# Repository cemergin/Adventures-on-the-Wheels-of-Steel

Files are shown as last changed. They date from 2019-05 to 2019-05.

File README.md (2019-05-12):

# Adventures on the Wheels of Steel<sup>*</sup>

### Place blocks on the turntable

### Make some noise!

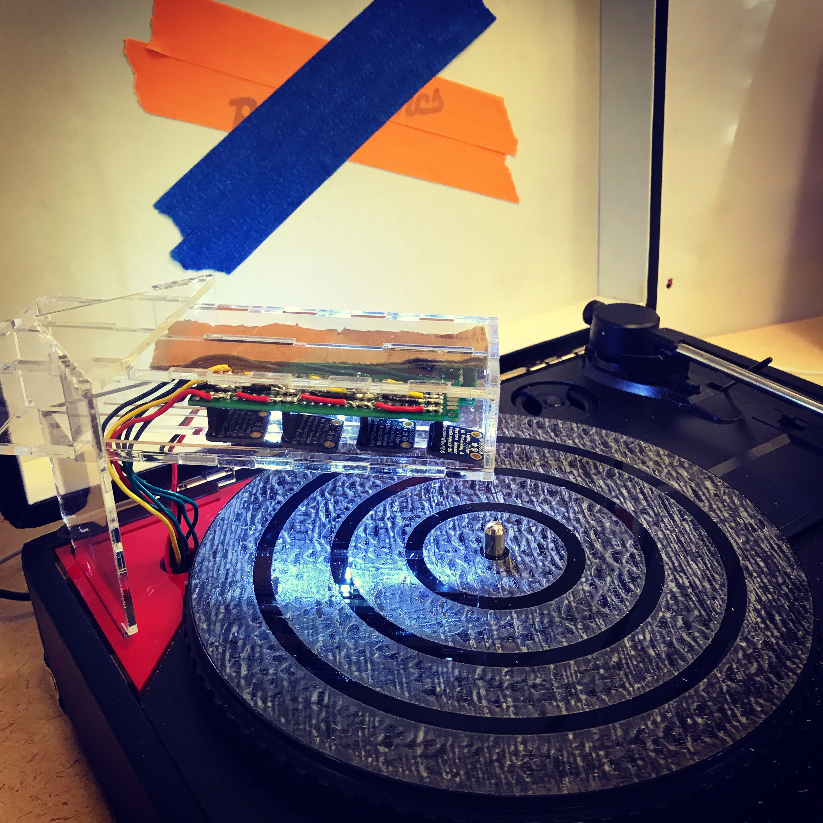
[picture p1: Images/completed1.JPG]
Adventures on the Wheels of Steel


## What is this?

*Adventures on the Wheels of Steel* is a tangible sequencer that allows users to create their own MIDI patterns by placing small objects, in this case lego blocks covered with colored tape, on a rotating disk found on turntables. The physical interface allows users to make beats, play chords or notes using the 4 channels. All channels are equiped with color recognition which creates room for greater variability. It utilizes Arduino Leonardo's native USB connectivity to tranfer MIDI messages to any Digital Audio Workstation imagenable. 
 
## Why is this made? 

The project has been created as part of 49-719 *Internet of Things - In Depth* class that I've attended at Carnegie Mellon University during Spring 2019 semester. *Adventures on the Wheels of Steel* pays homage to the legendary Grand Master Flash, who single handedly redefined the use of turntables in music, while investigating how tangible interfaces can ease and enchant the idea generation process during music making. 

## How did I end up here?

When I first entered electrical engineering school back in 2012, I had a dream of creating electronic music instruments, guitar pedals and amplifiers. Unfortunately, I learnt the hard way that undergraduate engineering school is not really the place where dreams come true. This is not true for graduate education though.

Long story short, when I was given the chance to work on any project idea I want for 6 weeks, I knew that I was going to create something to do with music. All the pieces came together when I stumbled upon the Beat Blox project created by Per Holmquist. I looked at his take on the turntable as a tool to create music and said "I can make that". Then for 6 weeks I focused my energy on replicating his design and trying to find ways of adding features that can make it more expressive and adaptable. I thought that to create a real music making tool, I needed to integrate MIDI to the design and add a way of creating variation.  

### Inspiration

I got most of my inspiration from this project. Its simple beautiful at the same time. Check it out before you continue to understand where I'm coming from.

[Beat Blox by Per Holmquist](https://open.spotify.com/track/7xMzNQkDzu3JZkhURGvH7p?si=wFec3MJkSc-wyBhV8cBQGQ)

### Forerunners

Tangible interfaces are not anything new for electronic music making tools. Here are some of the recent examples that I looked at while working on my design. The beauty of making things with technology is that when you figure out a way to make a particular tool, adapting your findings to create designs that are similar on the inside but different on the outside is easy. So here are some inspiration for everyone who wants to create their own MIDI controllers.   

[Spinning Disc Step Sequencer](https://learn.adafruit.com/spinning-disc-step-sequencer/overview)

[Coin Sequencer](http://www.varal.org/coinsequencer/)

[Tquencer](https://jensvetter.de/files/pdf/tquencer_acm.pdf)

[UTS-1](https://www.youtube.com/watch?v=3NAn9fSdh8M)

[XOXX Composer](http://xoxxcomposer.axelbluhme.se/)

## How can you make this? 

I've listed the components I used along with schematics and lasercutting patterns to recreate what I made below but I highyl recommend you look at the tutorial I created about MIDI and creating MIDI instruments with Arduino using the ling below. 

[Basic Tutorial on MIDI](https://github.com/cemergin/Adventures-on-the-Wheels-of-Steel/blob/master/Tutorials/MIDI101_%231.md)

Just hook up the components the way I described below and upload the code and you will be good to go. Design physical enclosure to taste and start making some noise! I hacked a already existing record player to use its rotating disk but you don't have to. If you know more mechatronics than me just do your thing and go nuts! 

### Components

1. 1 x Arduino Leonardo
1. 1 x [SparkFun Multiplexer Breakout - 8 Channel](https://www.sparkfun.com/products/13906)
1. 1 x [Byron Statics Record Player](https://www.amazon.com/gp/product/B07J2NZLZS/ref=ppx_yo_dt_b_asin_title_o03_s00?ie=UTF8&psc=1)
1. 4 x [Adafruit APDS9940](https://www.adafruit.com/product/3595) 
1. 4 x [Adafruit LED Sequins - Warm White](https://www.adafruit.com/product/1758)

### Circuit 

#### Basic Circuit 

I used this circuit as a proof of concept for my idea and extended the capabilities from here. I feel like starting small is always easier when you are developing projects such as this one. 

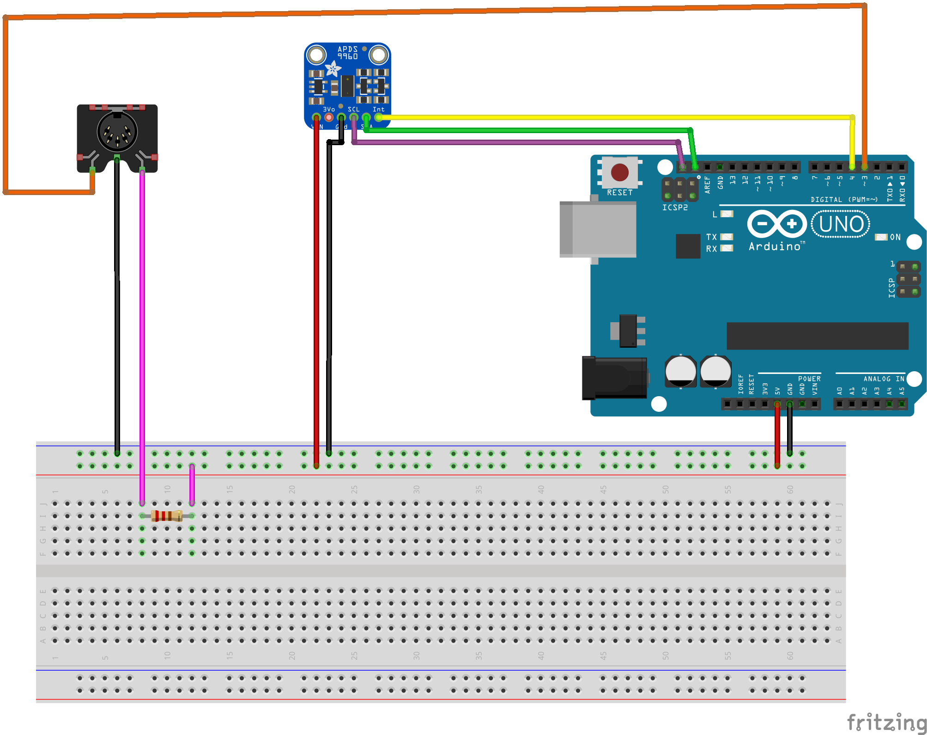
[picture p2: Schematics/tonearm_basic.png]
Basic Circuit


#### Initial Prototype

The initial prototype used a female MIDI jack to output MIDI information but that's not really convenient if you are mainly creating music with your computer. 

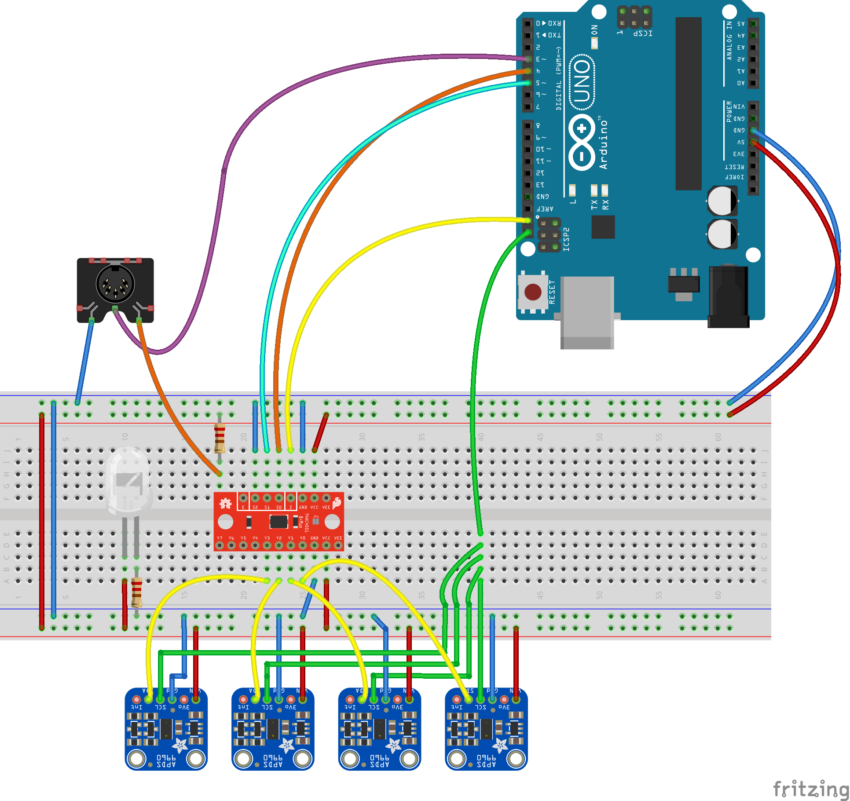
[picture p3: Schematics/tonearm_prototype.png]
Initial Prototype


#### Final Circuit

Arduino Leonardo for the resque!

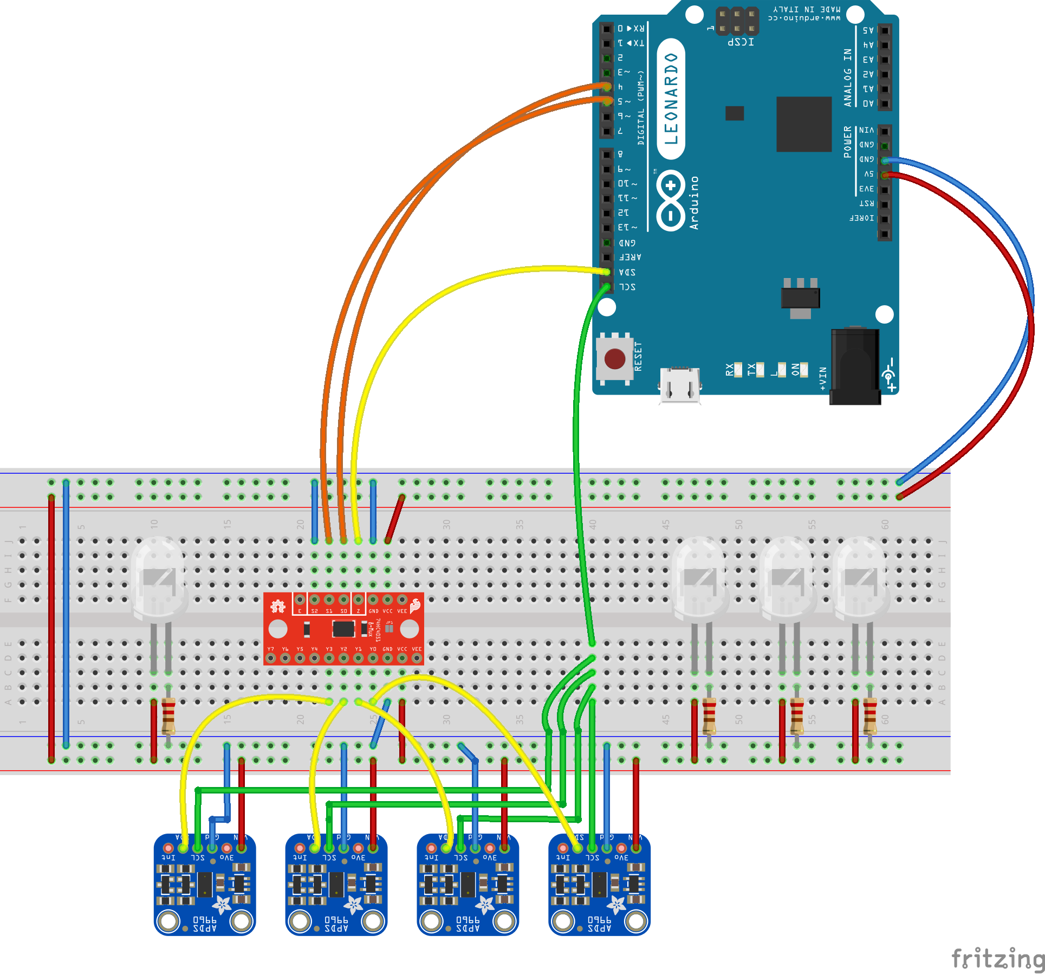
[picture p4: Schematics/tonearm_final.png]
Final Circuit


### Code

The code is pretty self explanatory. Check the comments I added to understand how it does what it does. 

[You can reach the final code here](/Code/tonearm.ino)

### Form  

First things first, I suck at CAD! On the other hand, I have a couple friends that are experts at it, so I got some help while designing the right enclosure for my circuit. 

#### "With A Little Help From My Friends"<sup>**</sup>

Final tonearm form designed by [Özgüç Bertuğ Çapunaman](https://github.com/ozgucbertug) on Rhino.

#### Tonearm

Tonearm Form

[Tonearm Lasercutting Pattern](tonearm.dxf)

## Related Resources

[Selfmade Tutorial on MIDI & Arduino](https://github.com/cemergin/Adventures-on-the-Wheels-of-Steel/blob/master/Tutorials/MIDI101_%231.md)

[Introduction to MIDI by the MIDI Association](https://www.midi.org/images/easyblog_articles/43/intromidi.pdf)

[MIDI Message Codes Explained](http://www.songstuff.com/recording/article/midi_message_format/)

[Arduino MIDI Output Basics](https://www.midi.org/articles-old/arduino-midi-output-basics)

[MIDI Output Using an Arduino](http://itp.nyu.edu/physcomp/labs/labs-serial-communication/lab-midi-output-using-an-arduino/)

[Arduino MIDIUSB Library](https://www.arduino.cc/en/Reference/MIDIUSB)

## Notes

* [Grandmaster Flash & the Furious Five - Adventures of Grand Master Flash On the Wheels of Steel](https://open.spotify.com/track/7xMzNQkDzu3JZkhURGvH7p?si=wFec3MJkSc-wyBhV8cBQGQ)

** [The Beatles - With A Little Help From My Friends](https://open.spotify.com/track/2RnPATK99oGOZygnD2GTO6?si=fi9PeBmyTsGBMCBx69-2zQ)

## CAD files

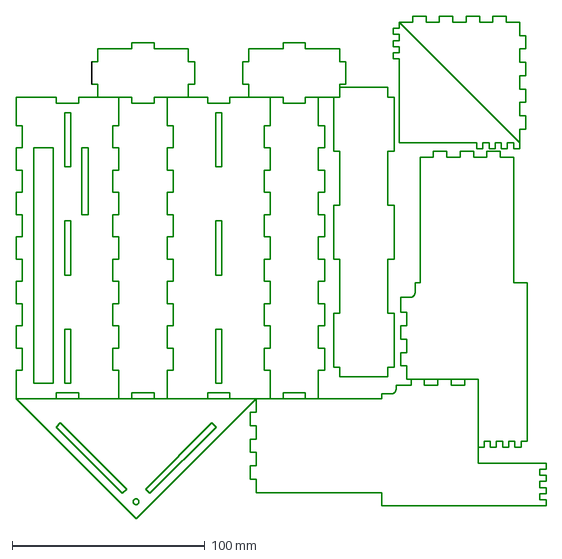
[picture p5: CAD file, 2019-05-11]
Form/tonearm.dxf
274.6 x 260.6 mm

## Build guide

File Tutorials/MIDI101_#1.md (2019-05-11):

# Introduction to MIDI (Pt.1)

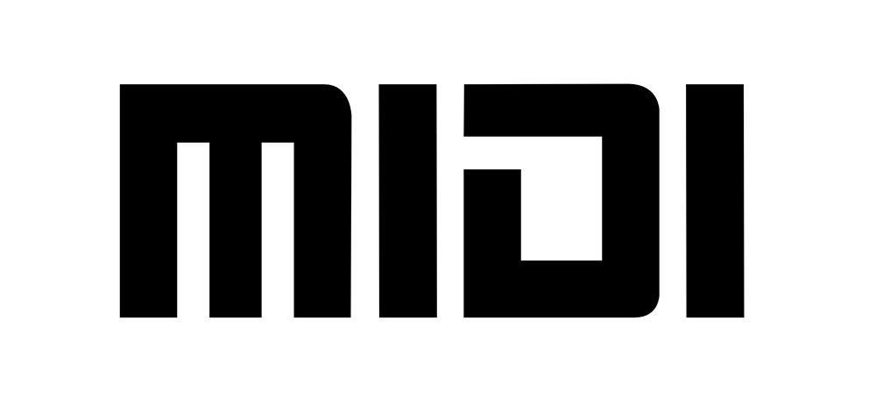
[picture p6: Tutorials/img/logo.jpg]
MIDI LOGO


# What is MIDI anyway?

Musical Instrument Digital Interface or better known as MIDI, is a technical standard that allows digital instructions to be sent between electronic music instruments and computers. The infamous standard incorporates a communication protocol, a digital interface and electrical connectors which in combination allows the communication of a variety of audio devices. 
 
MIDI instructions consist of simple digital data only! These instructions transfer information about pitch, tempo and velocity of musical notes. There are no actual audio signals involved. This aspect alone makes MIDI really compact, editable and easy to move around because the consumed disk space is thousand times less compared to an equivalent recorded audio. Musicians all around the world use it to play, edit and record music! 

Here's a simple flowchart to help you understand how it works.

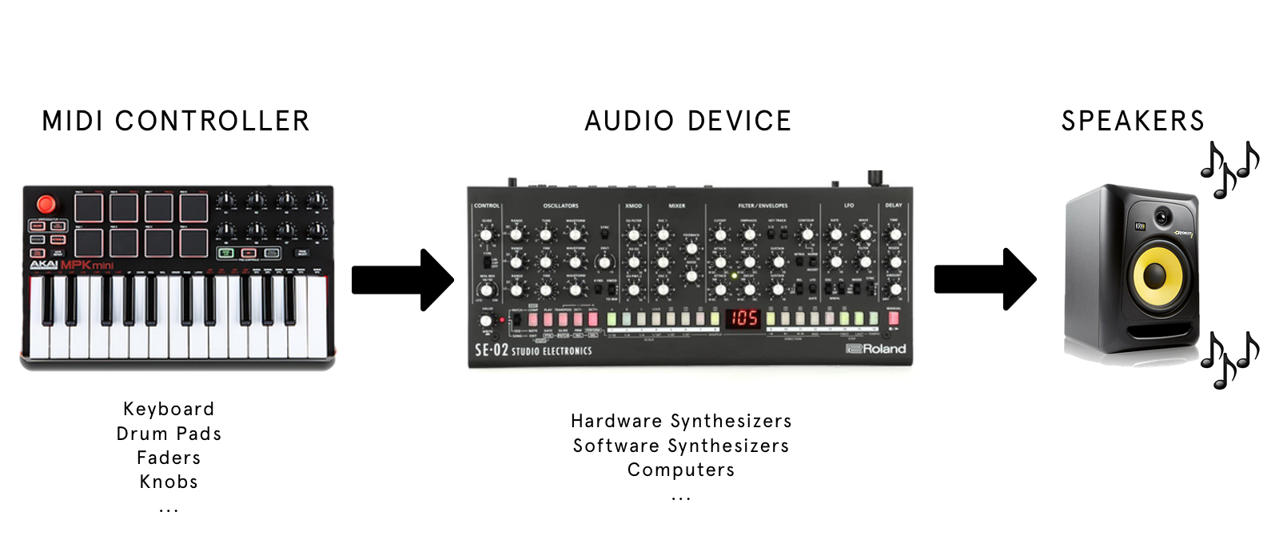
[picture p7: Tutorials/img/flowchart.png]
Simple flow Diagram


In simple terms, MIDI works like sheet music for electronic devices read and play. 

In more technical terms, MIDI messages work like computer code, they help generate and transfer instructions for electronic audio devices. A MIDI source, such as a keyboard, generates these instructions and through the MIDI cables, transfers them to an audio device. The audio device which is usually a synthesizer of some sort, in turn translates the instructions into real audio. 

The MIDI system is actually really similar to “player piano” if there any Western fans out there. Look closely to the sheet of paper that is rolling on the piano, you will see lines that are etched on it which instructs the mechanism which notes to play and for how long.  

### Player Piano

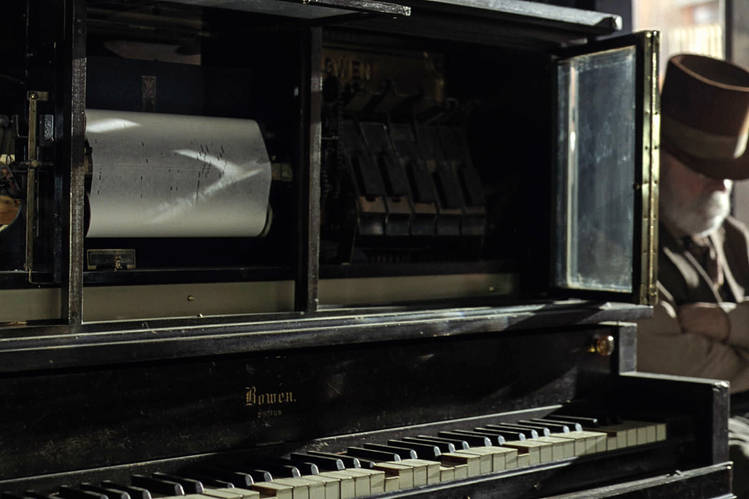
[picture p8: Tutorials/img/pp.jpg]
Player Piano


[The Entertainer on a player piano](https://www.youtube.com/watch?v=aseMAEctM1s)

Here’s how a MIDI file of Pokemon Red’s Pokecenter theme looks like on my Digital Audio Workstation. The annotations showcase some of the different types of information that can be transferred with MIDI.

This is how Ableton Live's piano roll looks like when I added the Pokecenter theme from the Pokemon Red game!

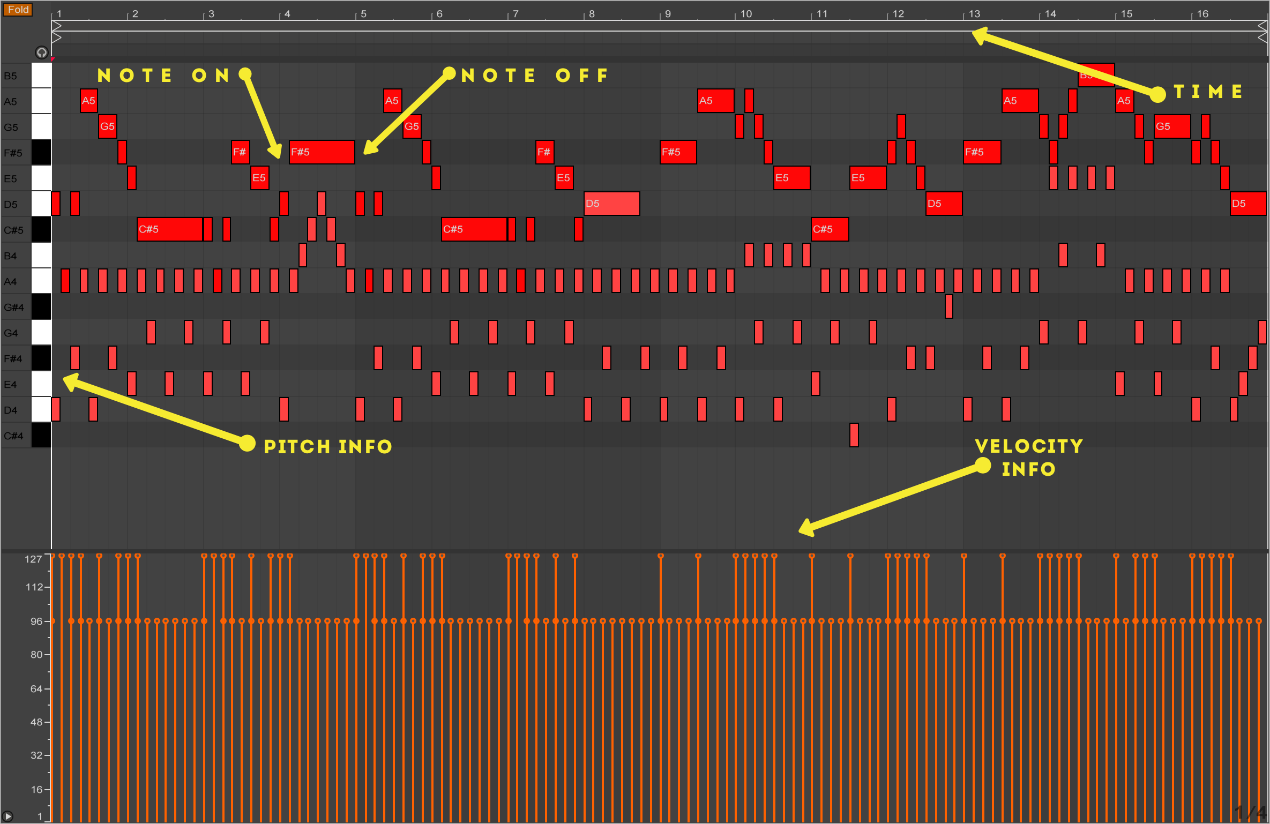
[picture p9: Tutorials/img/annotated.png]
Pokemon Song Picture


# Some History

As it turns out, there was no standardized way of connecting or synchronizing electronic music instruments manufactured by different companies in the early 1980s. Every manufacturer was trying to come up with their own way of communication between instruments. 

The founder of Roland, a company that has shaped the face of music multiple times in the last 50 years, Ikutaro Kakehashi felt that the lack of standardization was limiting the growth of the electronic music industry. He reached out to Sequential Circuits’s Dave Smith, another legendary name in the electronic music industry, about creating a cheap and simple standard in 1981. 

The initial standard was shown in November 1981 during the Audio Engineering Society and the first synthesizers that were equipped with MIDI hit the shelves in 1982. The rest was history! 

## Rolan Jupiter-6 one of the first two synthesizers with MIDI connectivity

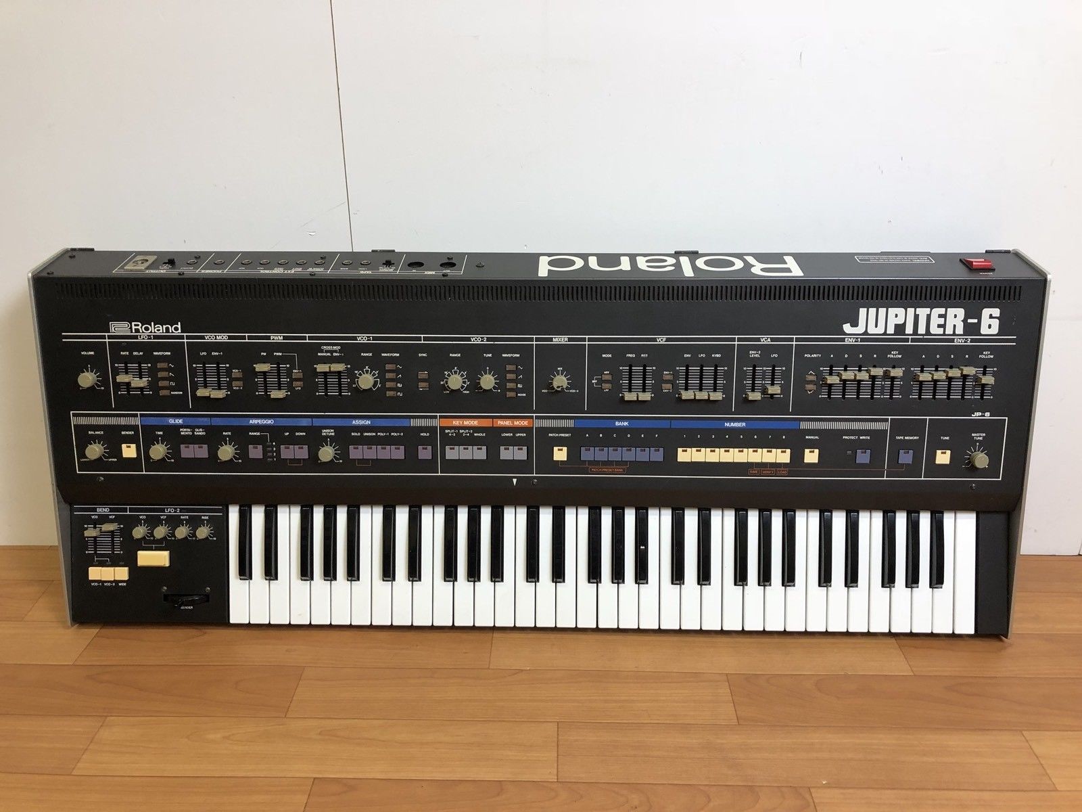
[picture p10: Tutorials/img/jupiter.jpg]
Roland Jupiter-6


No wonder there was a techno boom in the early 1990s all around the world! 

# Working with MIDI

Here's where things start to get interesting! Let's look at how you can connect MIDI capable products to your own computer. 

### Things you will need

* Your computer
  * Any computer with a decent processor and RAM will do here but Digital Audio Workstation; aka DAWs, tend to get processing heavy as the number of intrument channels increase. Since we are going to work with basic stuff, you should be alright with your good old laptop.
* A Digitial Audio Workstation
  * There are a lot of Digital Audio Workstations or DAWs out there. I use Ableton Live. You might also encounter Apple's Logic Pro, Steinberg's Cubase, Apple's Garage Band, FL Studio, Presonus Studio One, Propellerhead Reason, Avid's Pro Tools.. The list goes on and on. People who are into music production use more than one as each of them have their own pros and cons. Unfortunately, most of them are paid applications but if you don't want to break your piggy bank, there are ways around this which I'm not going to get into here ;) Just do a little Google search! 
* A software synthesizer
  * Luckyl, most DAWs come with a bunch of software synthesizers to play with! There are also numerous software syhtnesizers out there in the digital world. Some are free but most of them aren't cheap. Watch some Youtube reviews to make up your mind if you are interested. 
* A MIDI Controller
  * Any controller with MIDI capabilities work here. I have a Novation Launchkey 49 USB Keyboard at the moment which I will be using during this tutorial but your MIDI device doesnt have to be a keyboard. For example, Akai Professional's Pad controllers are also really fun to play with. The Karg nanoKey family is a good place to start. If you want to go hard with a lot of controls such as trigger pads, faders and knobs you might look into Arturia's KeyLab mkII series. Be warned though, they are not cheap.
  * One thing to distinguish here! Most of the controllers that are available on the market today connect to your computer through USB. Most of them also have the original MIDI inputs and outputs but they are seldom used to connect to computers. They are mostly there to communciate to analog synthesizers. The glorious days of using the original MIDI connection to make music may be past but the you can still run into some MIDI cables here and there.
* A soundcard with MIDI Input (Optional / Read Details) 
  * If you don't have a USB connected controller, you need a device to convert those MIDI messages for your computer to understand wats happening. Most USB connected soundcard have MIDI input and output today. So you might as well get one fi you are going to play with your fathers MIDI controllers that are collecting dust in the attic. 
  * Getting a soundcard will help with the latency issues during your recordings and production as most computers cannot really cope well with digital-2-analog conversion of signals. 
  * I'm using Roland's Quadcapture for a while now. I like it and its a good place to start. If you want other options look into brands like M-Audio, Focusrite, MOTU. If you don't want to take my word for it Google is your biggest companinon into the world of electronic music production. 
* A Male-Male MIDI Cable (Optional / Read Details) 
  * As you might guess, if you have a USB connected MIDI controller, you can skip this step but its always good to have one as MIDI cables can come in handy in situations where you work with olders synthesizers. 
* USB Cable(s) (Not so optional!)
  * I think you started to get the idea here. If you have USB connected tools like your MIDI controller or your soundcard, you better have a USB cable to connect them to your computer. 
 
# Let's Get Down to Business

### Follow These 5 Easy Steps To Start Producing Music 

1. Connect Your Controller To Your Computer
  1. How to connect your USB Controller
    1. This one is pretty self explanatory! Just find the appropriate USB cable for your controller and plug it in to your computer!
  1. How to connect with a MIDI Cable
    1. Similar to the USB Controller option, just connect Your Soundcard Through USB!
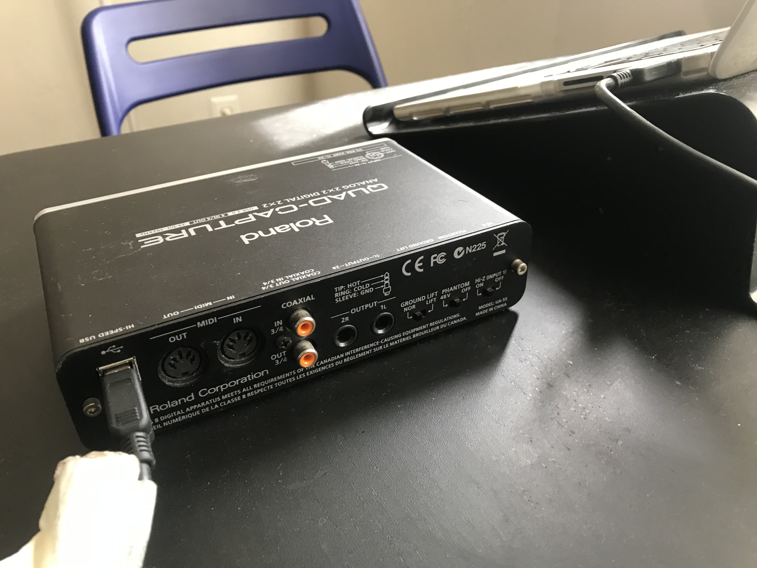
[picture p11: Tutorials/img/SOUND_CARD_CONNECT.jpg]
Connect Your Soundcard Through USB
    1. 
    1. Get your MIDI Cable & locate the MIDI Input
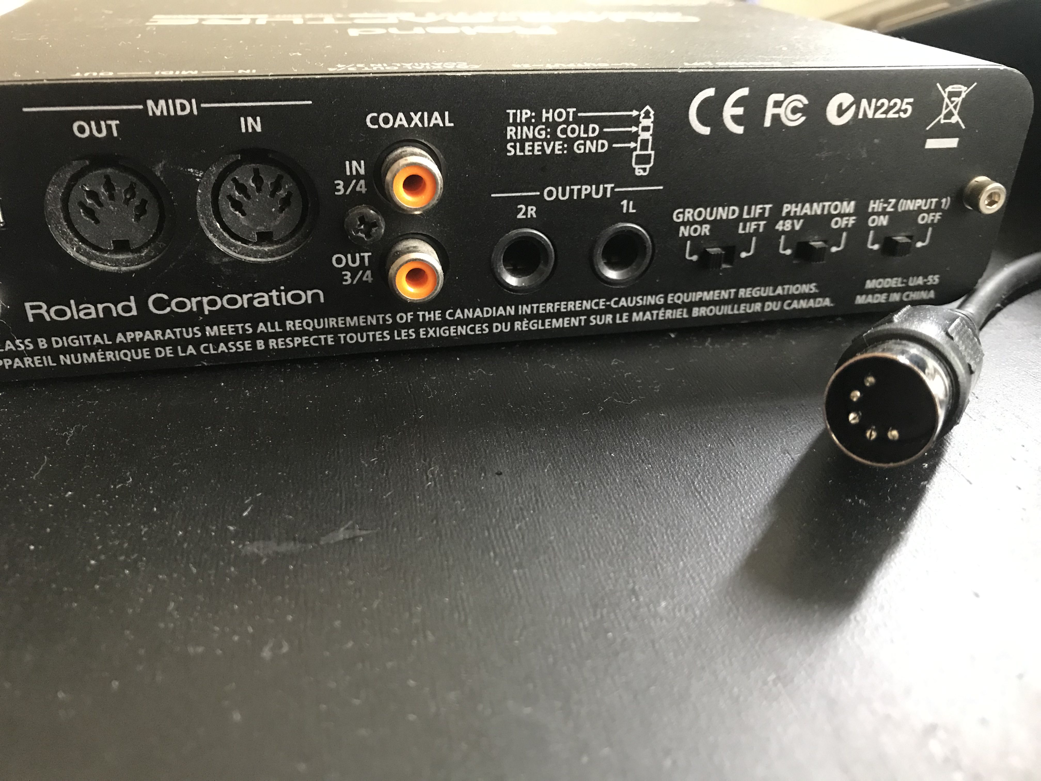
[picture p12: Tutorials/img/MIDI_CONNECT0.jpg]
Get your MIDI Cable & locate the MIDI Input
    1. 
    1. Connect MIDI Cable to MIDI Input Pin of your soundcard
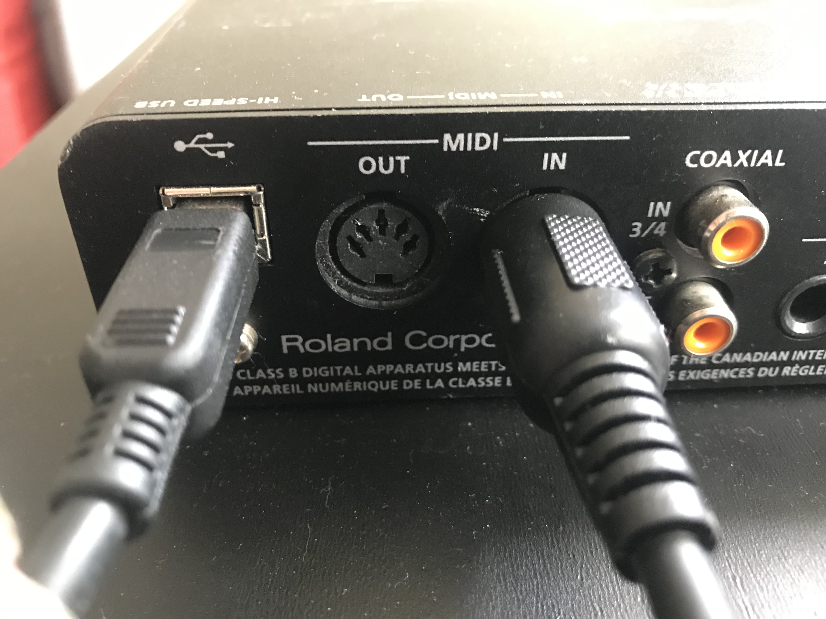
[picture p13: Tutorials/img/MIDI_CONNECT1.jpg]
Connect MIDI Cable to MIDI Input Pin of your soundcard
    1. 
    1. Connect the other end of your MIDI cable to MIDI Output device
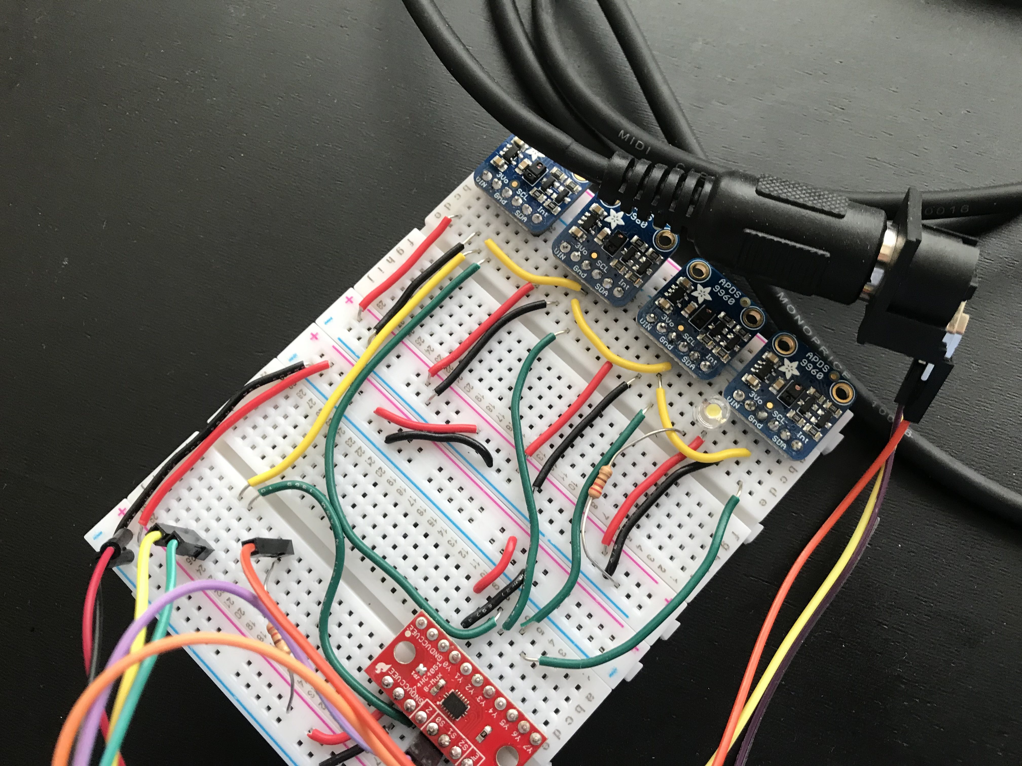
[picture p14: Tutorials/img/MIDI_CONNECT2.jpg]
Connect the other end of your MIDI cable to MIDI Output device
    1. 
1. Go to your DAW of choice
  1. Open up your DAW of choice. I'm using Ableton Live 9 here and this is how it looks like when I start it up.
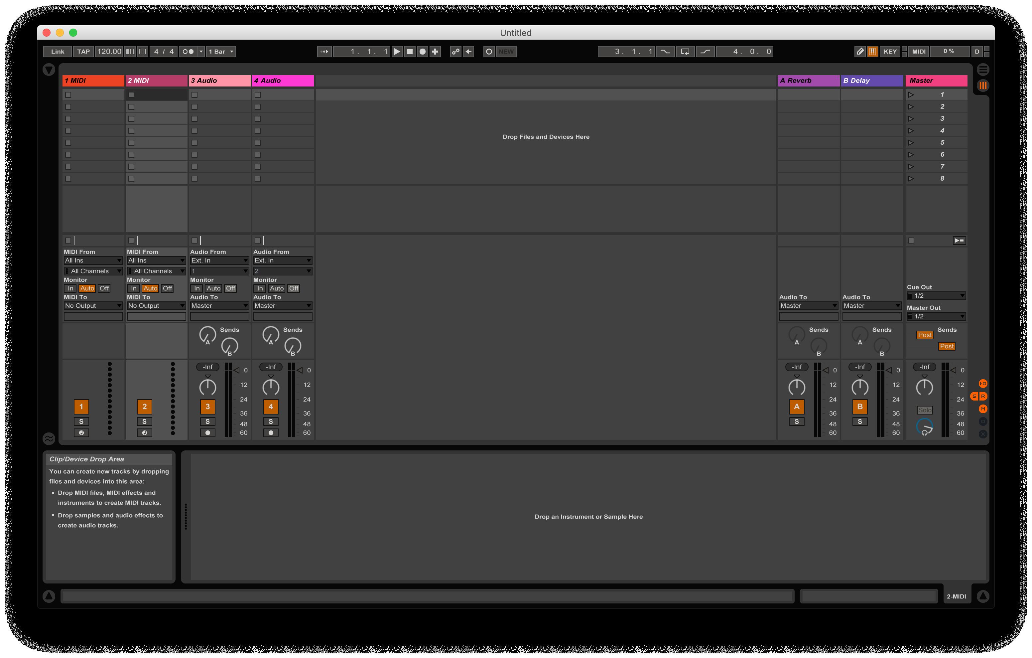
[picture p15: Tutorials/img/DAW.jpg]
How Ableton looks like
     
1. Throw your instrument of choice in the mix!
  1. Add your insturment of choice to the MIDI channel you want to work on your DAW. A simple drag and drop should work for Ableton. I used a instrument named Analog that ships with Ableton. 
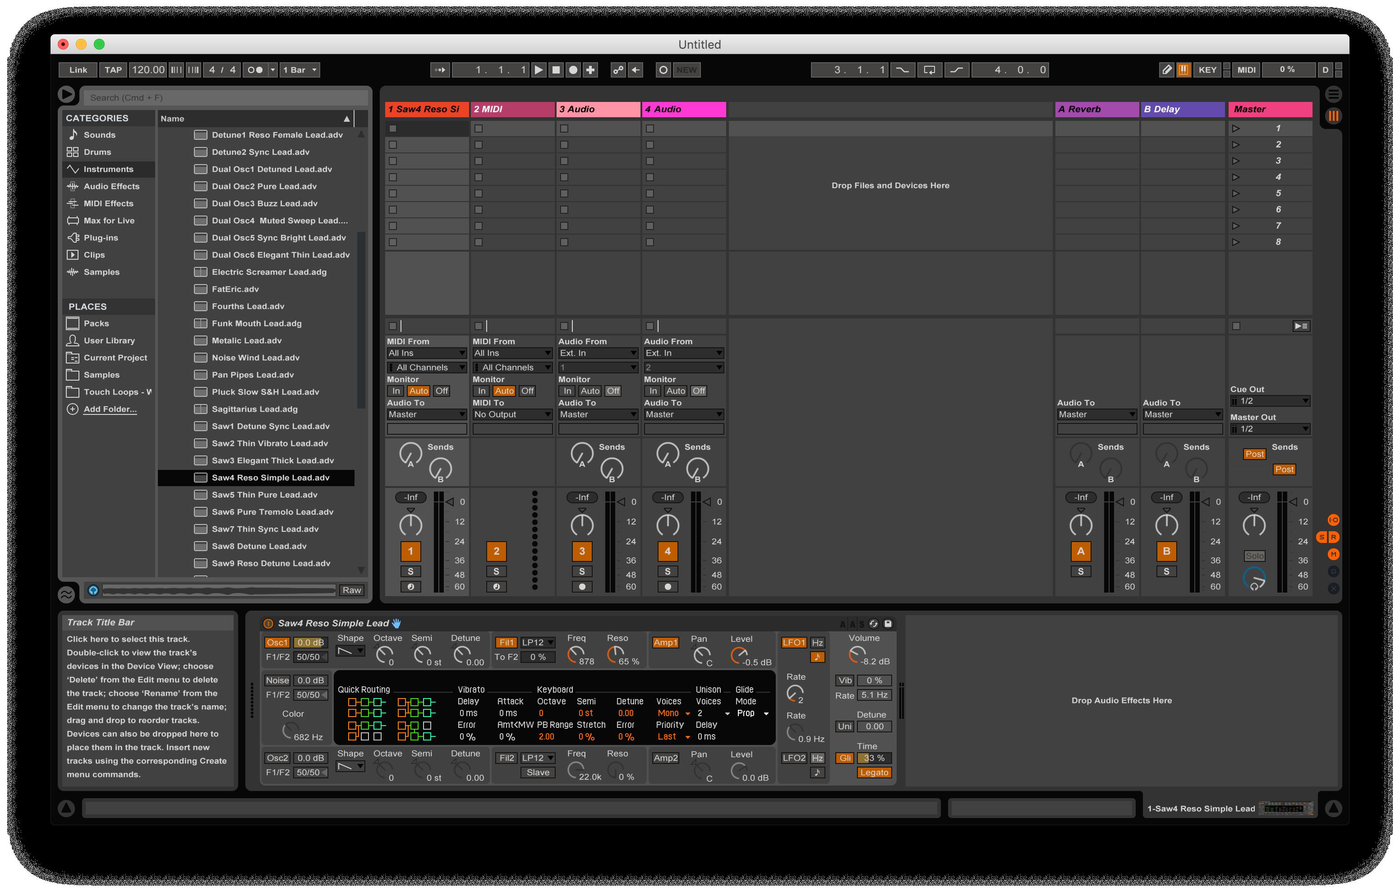
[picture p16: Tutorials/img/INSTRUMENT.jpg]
Choose an software sytnhesizer
     
1. Fiddling With Settings
   1. Now we need to let our DAW know which MIDI device were are looking for.
   1. Look at the MIDI input settings on your MIDI channel.
   1. Choose the right controller for your input.
     1. My Novation controller that I hooked up through USB looks something like this.
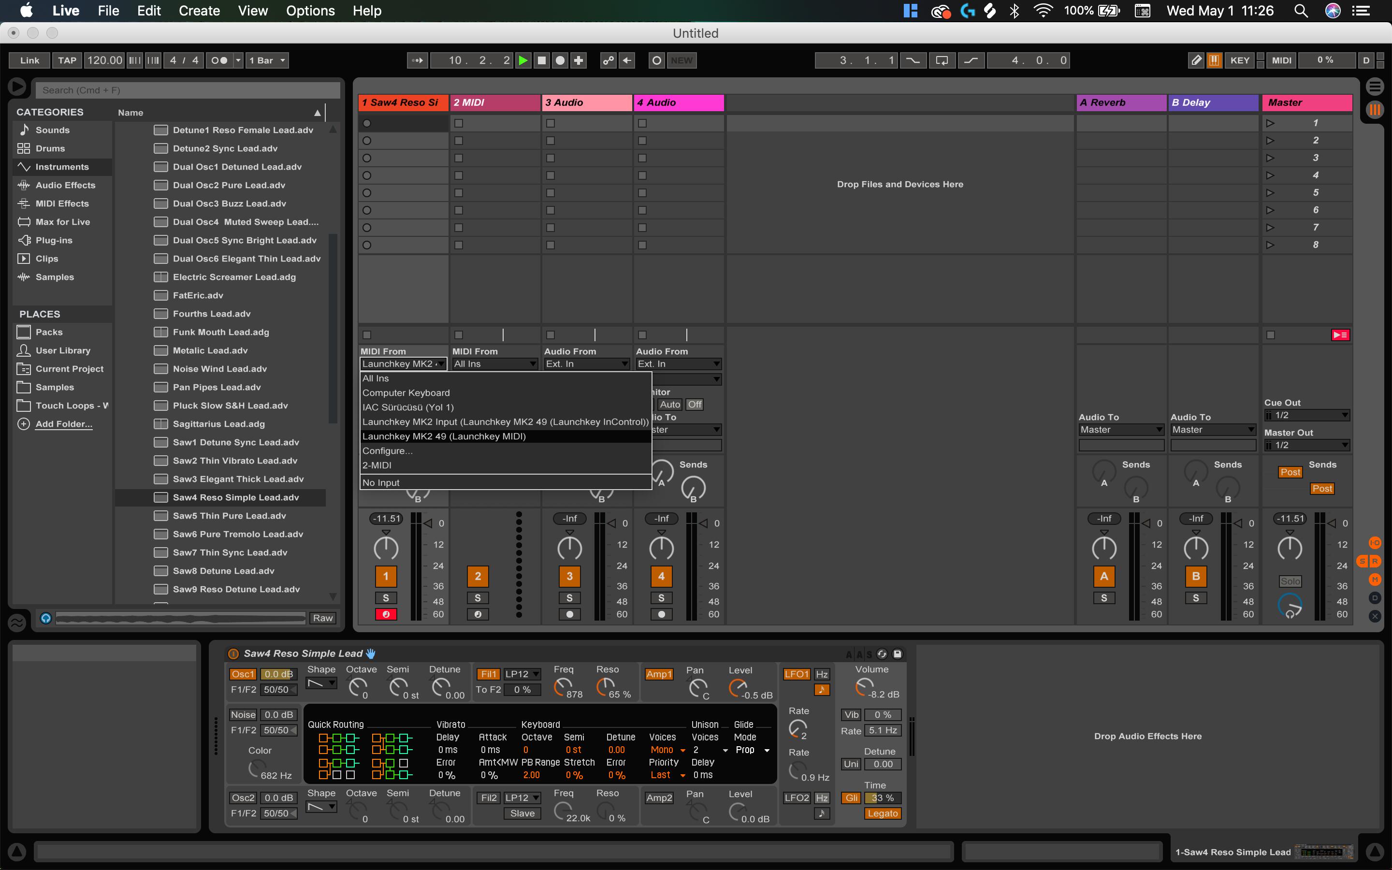
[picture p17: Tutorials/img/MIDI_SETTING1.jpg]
MIDI Settings no#1
     
     1. If you are using a Soundcard to communicate the MIDI messages to your computer. You should look for your Soundcard's name there.
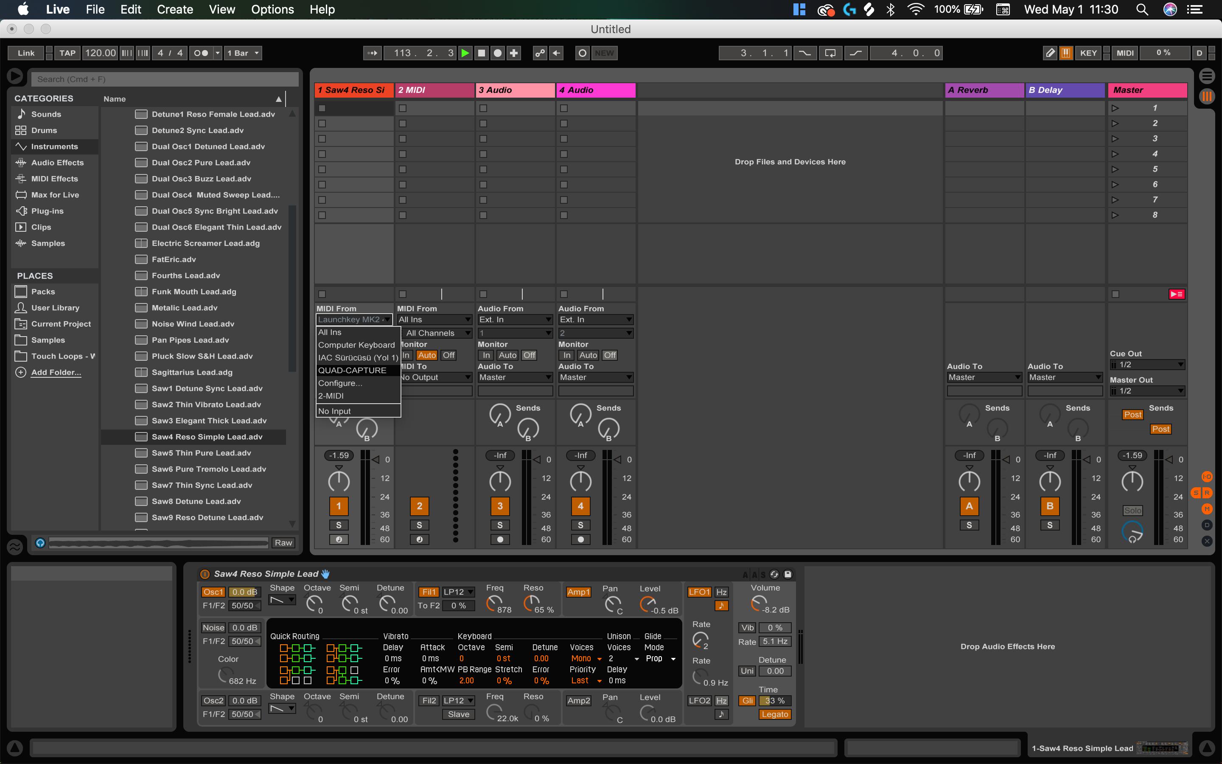
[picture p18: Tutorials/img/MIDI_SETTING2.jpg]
MIDI Settings no#2
     
1. Start pushing some buttons
1. Make some noise!

If this sound to you easy we will look into making our own simple MIDI controller in the next! 

Use the link below to see how that's done. 

/// [2nd Part of Tutorial Here!](https://github.com/cemergin/Adventures-on-the-Wheels-of-Steel/blob/master/Tutorials/MIDI101_%232.md) ///

# Reading Material

[More on what MIDI is](https://blog.landr.com/what-is-midi/)

[Introduction to MIDI by the MIDI Association](https://www.midi.org/images/easyblog_articles/43/intromidi.pdf)

[Ableton Live](https://www.ableton.com/en/)

[Roland Quad-Capture](https://www.roland.com/us/products/quad-capture/)

[Novation Launchkey](https://novationmusic.com/keys/launchkey)

[The MIDI cable I recently bought](https://www.amazon.com/gp/product/B009GUP7U8/ref=ppx_yo_dt_b_asin_title_o05_s00?ie=UTF8&psc=1)

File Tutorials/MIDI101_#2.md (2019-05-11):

# Introduction to MIDI (Pt.2)

MIDI LOGO

# So you really want to play with MIDI?

Thanks for making this far in this tutorial!

In the first part, we looked into what MIDI is, some of its history and how you can anyone hook up a MIDI controller to your computer and play around with it. Here we are going to get into the nitty gritty of creating a MIDI controller with Arduino for creative programming projects. 

If that's not what you need, you can stop here and enjoy the this classic hip-hop track that I've shared for you below. 

[The Message by Grandmaster Flash & The Furious Five](https://www.youtube.com/watch?v=PobrSpMwKk4)

For those who about to rock with Arduino and MIDI, I salute you! Let's get going.

## Things you will need to get started
* Your computer
* An Arduino Uno
* A momentary switch
* 5-pin Female MIDI Socket
* 220-ohm and 10k-ohm Resistors
* A breadboard

### The schematic from Sprint #1

I'm just showing off here, a little. This is the circuit I used for Sprint #2. We are going to do something even more basic so that you can scale things up yourself if you want to. 

Schematic

### The actual schematic for the tutorial.

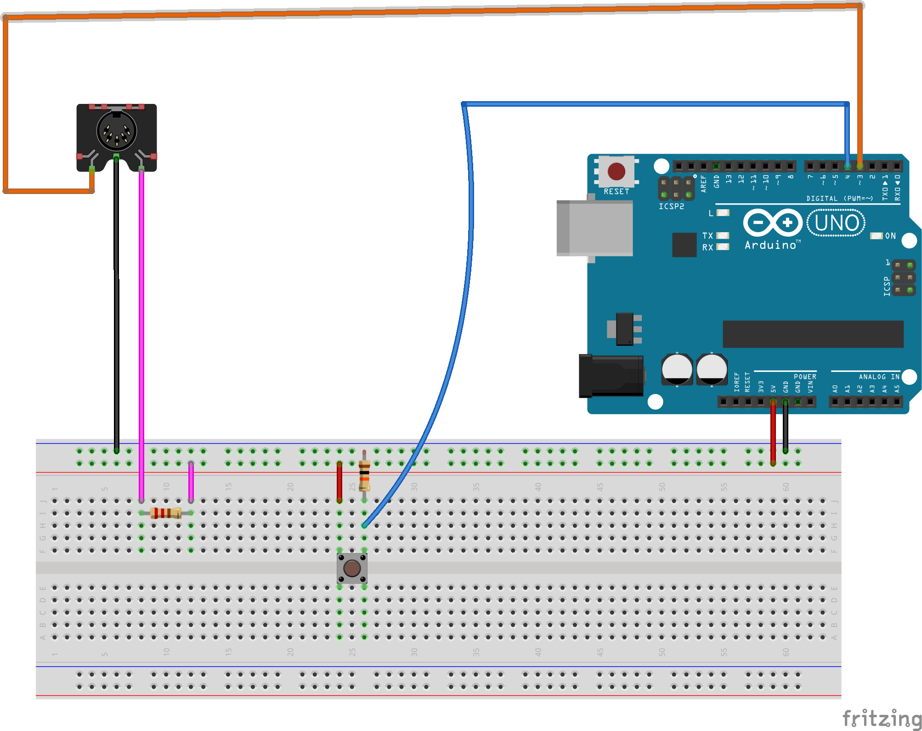
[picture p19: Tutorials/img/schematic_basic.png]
Schematic_basic


# The Code

I've added comments in the code to help you understand what is what. If you have any questions feel free to check the links I've provided below for more information or to ask me in person! 

There are lot more MIDI messages out there you can play with other than note on note off. If you want to control different parameters in your DAW like filter frequency, modulation, attack, sustain, release, decay, reverb send, etc. You can look into CC messages and try adding an Analog input component like an potentiometer and working with it. I'm not going to go super in-depth to scare you off.  

```
// Serial MIDI Dependencies
#include <SoftwareSerial.h>

// Button Input
#define BUTTON_PIN 4

// Software Serial Instance
SoftwareSerial midiSerial(2,3); 

// Boolean to keep check if the button is still being pressed
bool buttonPressed = false;

// Variable to read the button state
int currentSwitchState = 0;

// MIDI Note Variables
byte MIDI_Note = 60;

void setup() {  

  pinMode(BUTTON_PIN, INPUT);

  // Serial Begin
  Serial.begin(115200);
  midiSerial.begin(31250);
  
  // For those about to rock I salute you!
  Serial.println("Adventures on my simple tutorial on creating a Arduino MIDI controller");
  Serial.println("Have fun and don't forget to make some noise!");
  
}

void loop() {
  // Read the button state
  currentSwitchState = digitalRead(BUTTON_PIN);
  
  if(currentSwitchState == 1){
    if(!buttonPressed) {
      // Button is pressed send play note
      buttonPressed = true;

      // 0x90 refers to a message that plays or stops notes
      // We use our prespecified MIDI Note byte but you can change that if you want
      // 0x40 refers to the velocity of 64, you can also play with this if you want to get louder
      sendMIDIMessage(0x90, MIDI_Note,0x40);
      }
    } else {
      if(buttonPressed)
      {
      // Button is released stop notes
      // If you send a MIDI Note message with 0x00 velocity the note is stopped by the synthesizer
      sendMIDIMessage(0x90, MIDI_Note,0x00);
      buttonPressed = false;
      }
    }
}

  //  Sends a MIDI message through the MIDI Socket. 
  // Warning: This function doesn't check to see that cmd parameter is greater than 127
  // Warning: This function also doesn't chech to see if the data values are less than 127
  // FYI: These parameters are supposed to be between 0 - 127
  // Read more about MIDI messages if you are interested in learning why!
  
  void sendMIDIMessage(byte cmd, byte data1, byte data2) {
    midiSerial.write(cmd);
    midiSerial.write(data1);
    midiSerial.write(data2);

     //prints the values in the serial monitor to feast our eyes with our progress
    Serial.print("Command: ");
    Serial.print(cmd);
    Serial.print(", Data 1: ");
    Serial.print(data1);
    Serial.print(", Data 2: ");
    Serial.println(data2);
}
```

# More Reading Material

[Another basic Arduino tutorial](http://itp.nyu.edu/physcomp/labs/labs-serial-communication/lab-midi-output-using-an-arduino/)

[An Instructable tutorial to look at](https://www.instructables.com/id/Send-and-Receive-MIDI-with-Arduino/)

[Parts Not Included also makes nice tutorials](https://www.partsnotincluded.com/arduino/how-to-control-anything-on-arduino-using-midi/)

[You can never go wrong with Hackaday Tutorials](https://hackaday.com/2019/04/06/make-your-own-midi-controller-with-an-arduino/)

[If you want to create a USB Controller I found this tutorial really helpful](http://blog.stekgreif.com/?p=699)

[MIDI Message Codes Explained](http://www.songstuff.com/recording/article/midi_message_format/)

[Arduino MIDI Library used to create a USB MIDI Controller](http://fortyseveneffects.github.io/arduino_midi_library/)

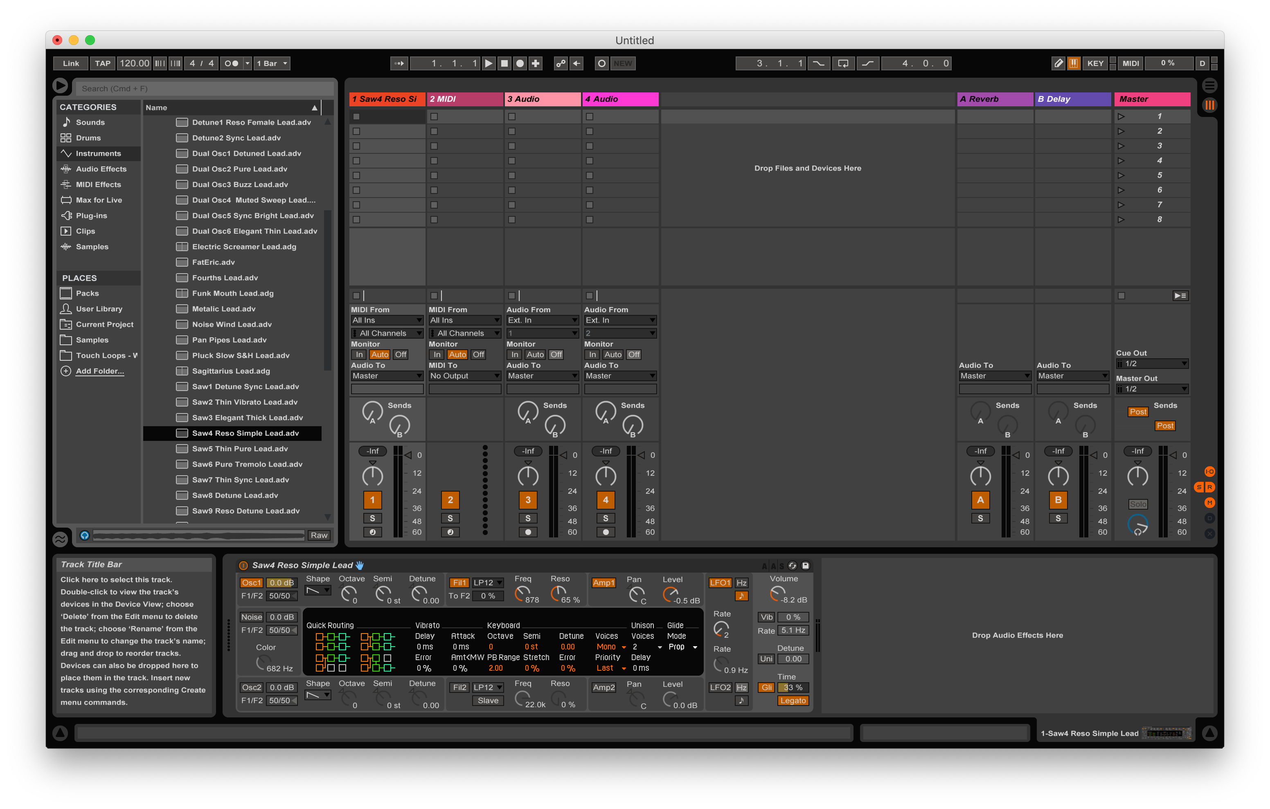
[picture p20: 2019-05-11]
Tutorials/img/INSTRUMENT.png

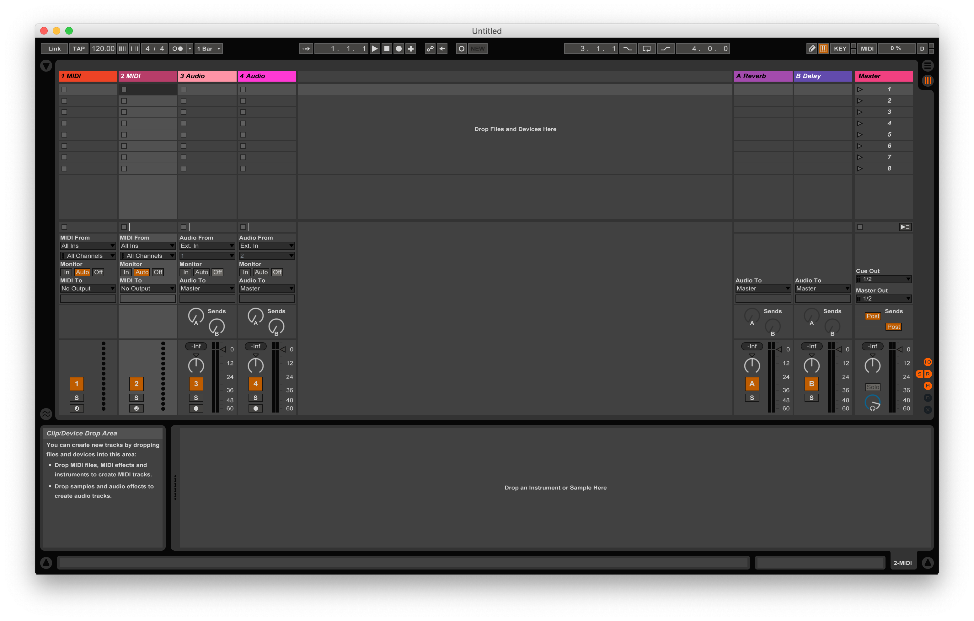
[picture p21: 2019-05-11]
Tutorials/img/DAW.png

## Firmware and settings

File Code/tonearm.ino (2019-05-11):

/*
 * Project Adventures of Cem on the Wheels of Steel
 * Description: Inspired by Per Holmquist's 'Beat Blox' project, I'm trying to develop my own MIDI controller that uses 4 Adafruit APDS9960 proximity sensors that allows users to create their own beats. 
 * The sequence created physically on a rotating disk; a wheel of steel, will be converted to MIDI information and fed to a Digital Audio Workstation such as Ableton Live through USB to be turned and be converted into music.
 * Components: Adafruit APDS9960, SparkFun PID 13906
 * Author: Cem Ergin
 * Date: May 10th 2019
 */

// MIDI USB Dependencies
#include <pitchToFrequency.h>
#include <pitchToNote.h>
#include <frequencyToNote.h>
#include <MIDIUSB_Defs.h>
#include <MIDIUSB.h>

// Proximity Sensor Dependencies
#include <Adafruit_APDS9960.h>

// DEBUG 
#define SHOULD_DEBUG 1

// NUMBER OF CHANNELS
#define NUM_CHANNELS 4

// VARIABLES FOR SELECTOR OUTPUT
#define SELECTOR_ONE 4
#define SELECTOR_TWO 5

// FIRST NOTE IN SERIES
const int NOTE_ONE = 60;

// APDS9960 Instant
Adafruit_APDS9960 apds;
int proximityThreshold = 9; // Optimize to taste

// Note On Off Variables
int colorOffset = 0;

// Sensor Index to switch between sensors
int sensorIndex = 0;
bool noteOn[NUM_CHANNELS];
int midiNotes[NUM_CHANNELS * 2]; 
int lastNote[NUM_CHANNELS];

// Variables for Color Sensing
uint16_t red, green, blue, clear_light;

void setup() {
  // Digital Pin Setup
  pinMode(SELECTOR_ONE, OUTPUT);
  pinMode(SELECTOR_TWO, OUTPUT);

  // Start Serial Output
  Serial.begin(57600);

  // Welcome Message
  if(SHOULD_DEBUG) {
    Serial.println("Adventures on the Wheels of Steel");
    Serial.println("Have fun and don't forget to make some noise!");
  }
  
  // Setup Sensors
  setupSensors();

  // Initialize Note On Off Arrays
  setupNotes();

}

void loop() {
  
  // Reset colorOffset for each loop
  colorOffset = 0;

  // Check proximity reading
  int prox = apds.readProximity();

  if ( prox > proximityThreshold ) {
    if(!noteOn[sensorIndex]) {
      
      // Object got close, start note
      noteOn[sensorIndex] = true;

      // Check color of object
      apds.getColorData(&red, &green, &blue, &clear_light);

      // If more blue than red play variation
      if (blue > red) {
        colorOffset = NUM_CHANNELS;
      }

      // Record last note played for note off
      lastNote[sensorIndex] = midiNotes[sensorIndex + colorOffset];
        
      // Send note on MIDI message
      midiEventPacket_t noteOn = {0x09, 0x90, lastNote[sensorIndex], 100};
      MidiUSB.sendMIDI(noteOn);
      MidiUSB.flush();
      
      } 
      
  } else {
    if (noteOn[sensorIndex]) {
      // Object got away, end note
      noteOn[sensorIndex] = false;

      // Send note off MIDI message
      midiEventPacket_t noteOff = {0x09, 0x80, lastNote[sensorIndex], 0};
      MidiUSB.sendMIDI(noteOff);
      MidiUSB.flush();
      
      }
    
    }
  incrementSensorIndex();
}

// Sets up the noteOn, midiNote and lastNote arrays depending on NUM_CHANNELS
void setupNotes() {
  
  if(SHOULD_DEBUG) {
    Serial.println("Initializing MIDI Channels");
  }

  for ( int i = 0; i < NUM_CHANNELS; i++) {
    noteOn[i] = false;
    midiNotes[i] = NOTE_ONE + i;
    lastNote[i] = NOTE_ONE + i;
    midiNotes[i + NUM_CHANNELS] = NOTE_ONE + i + NUM_CHANNELS;
     
    if(SHOULD_DEBUG) {
    Serial.println("Channel #" + String(i) + " Notes: " + String(midiNotes[i]) + " & " + String(midiNotes[i+NUM_CHANNELS]));
    }
    
  }
 
  return;  

}

void setupSensors() {
  
  if(SHOULD_DEBUG) {
    Serial.println("Setting up APDS9960 Sensors");
  }
  // Reset sensorIndex just in case
  resetSensorIndex();
  selectSensor(sensorIndex);
  delay(10);

  for ( int i = 0; i < NUM_CHANNELS; i++) {
  if(!apds.begin()){
      if(SHOULD_DEBUG){
        Serial.println("Failed to initialize Sensor # " + String(sensorIndex) + " !");
       }
    } else {
        Serial.println("Sensor #" + String(sensorIndex) + " initialized!");  
    }
    apds.enableProximity(true); // Enable proximity mode
    apds.enableColor(true); // Enable color mode  
    incrementSensorIndex(); // Increement sensor index to setup next sensor
  }
  
  return;
    
}

void resetSensorIndex() {
  sensorIndex = 0;
}

// Selects sensor to read using SparkFun PID 13906
// Additional code is needed to allow more than 4 sensors to work
void selectSensor(int i) {
  int modulus = i % 2;
  int division = i / 2;

  if (modulus >= 1) {
    digitalWrite(SELECTOR_ONE, HIGH);
  } else {
    digitalWrite(SELECTOR_ONE, LOW);
  }

  if (division > 0) {
    digitalWrite(SELECTOR_TWO, HIGH);
  } else {
    digitalWrite(SELECTOR_TWO, LOW);
  }  
}

void incrementSensorIndex() {
  
  // Increment Sensor Index
  sensorIndex++;

  // If sensorIndex greater than number of channels reset 
  if ( sensorIndex >= NUM_CHANNELS ) {
    resetSensorIndex();
  } 

  // Break the news to the selector chip
  selectSensor(sensorIndex);  
}
